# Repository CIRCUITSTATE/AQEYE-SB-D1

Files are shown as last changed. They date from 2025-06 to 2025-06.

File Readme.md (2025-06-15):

# AQEYE-SB-D1

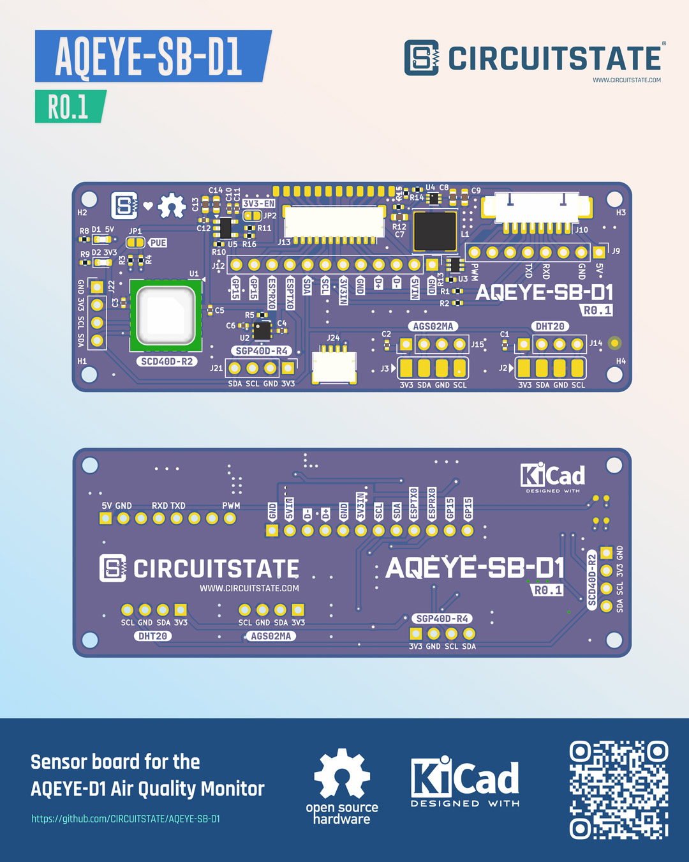
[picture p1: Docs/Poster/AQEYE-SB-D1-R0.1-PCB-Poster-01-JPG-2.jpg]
AQEYE-SB-D1 R0.1 Poster


[**AQEYE-SB-D1**](https://github.com/CIRCUITSTATE/AQEYE-SB-D1) is a PCB designed to hold the sensors for the AQEYE-D1 Air Quality Monitor project by CIRCUITSTATE Electronics. The board is designed to be connected to either the [**ESP32-S3-Touch-LCD-2.8**](https://www.waveshare.com/esp32-s3-touch-lcd-2.8.htm) from Waveshare or the AQEYE-MB-D1 main board. A separate sensor board was designed to keep the sensitive components away from external interferences such as noise, heat and other effects. This also makes it easier to replace the sensors or to add new sensors in the future without having to redesign the main board. AQEYE-SB-D1 is a completely open-source hardware (OSHW) project designed in the **KiCad** open-source EDA tool. **SB** stands for Sensor Board and **D1** is the first design variant of this project. You can download the source files of this design, modify them and redistribute them as you wish.

## Features

- Sensors
  - **Asair DHT20** temperature and humidity sensor.
  - **Asair AGS02MA** TVOC (Total Volatile Organic Compounds) sensor.
  - **Winsen ZH06** PM (Particulate Matter) sensor with PM1.0, PM2.5, PM10 measurement.
  - **Sensirion SCD40-D-R2** CO2 (Carbon Dioxide) sensor.
  - **Sensirion SGP40-D-R4** TVOC sensor.
- Connectors and solderpads for all sensors.
- 12-pin JST-SH connector for connecting to the main board.
- Selectable I2C pull-up resistors.
- **TPS61023** +5V boost converter to generate 5V from the 3.3V input for sensors that require 5V.
  - Output controlled by a GPIO pin.
- **AP22804AW5** based +3.3V load switch to control the power.
  - Controlled by a GPIO pin.
  - Jumper pad to constant enable.
- **LM66100DCKR** ideal diode based voltage ORing selector and reverse polarity protection for the 5V rail.
- Power indication LEDs for both 3.3V and 5V rails.
- Four M2 mounting holes.

## Design

- **Parent Project:** AQEYE-SB
- **Variant:** [AQEYE-SB-D1](https://github.com/CIRCUITSTATE/AQEYE-SB-D1)
- **Author:** Vishnu Mohanan (@vishnumaiea, @vizmohanan)
- **Latest Revision:** `R0.1`
- **Layer Count:** 2
- **Thickness:** 1.6 mm
- **Dimensions:** 80 x 30 mm
- **EDA Tool:** KiCad V9
- **License:** MIT

## Contributing

If you would like to contribute this project, you are welcome to post issues and feature requests on the **Issues** page. If you fork this project and created a new variant, you can let us know about it and get a unique identifier assigned for your project. The ID takes the following form.

```
Y<digit><letter><digit>
```

`Y` – Constant prefix.

`<digit>` – Digits from 0–9

`<letter>` – Characters from A–Z.

**Examples:**

```
Y1A1
Y1A2
Y2B1
Y3C4
```

The forked project should then be renamed to `AQEYE-SB-D1-<ID>` form.

**Guidelines:**

- IDs are assigned upon request. You can create a new issue to request a new ID once a fork is created. Keep the issue title as `Request New ID` and include a link to your fork in the description.
- You can either request a new ID that you like and that is already not chosen, or allow us to choose an ID for you.
- You should rename the original source files with the `AQEYE-SB-D1-<ID>` format.
- On the PCB, you can place the name of the project as `AQEYE-SB-D1` and keep the ID as a standalone text on any visible layers.
- Once a unique ID is assigned to a forked project, the revision should be reset to `R0.1`. Do not keep the original revision of the project.

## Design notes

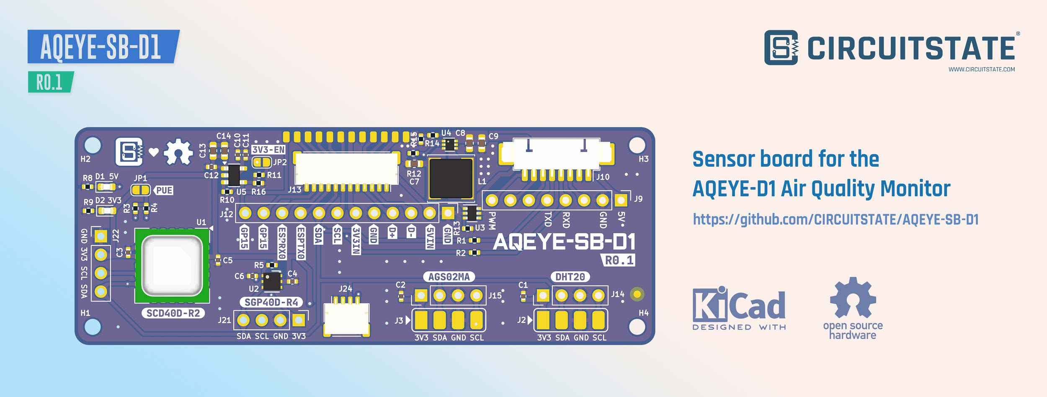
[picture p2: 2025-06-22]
Docs/Poster/AQEYE-SB-D1-R0.1-PCB-Poster-02-JPG-2.jpg

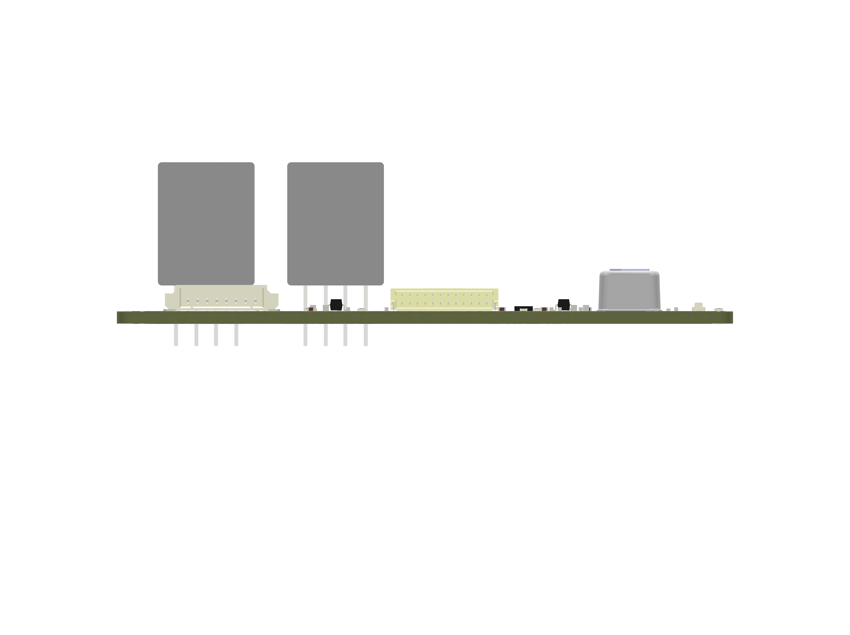
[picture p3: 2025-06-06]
Export/R0.1/2025-06-06/Renders/AQEYE-SB-D1-R0.1-PCB-Back-06062025-1.png

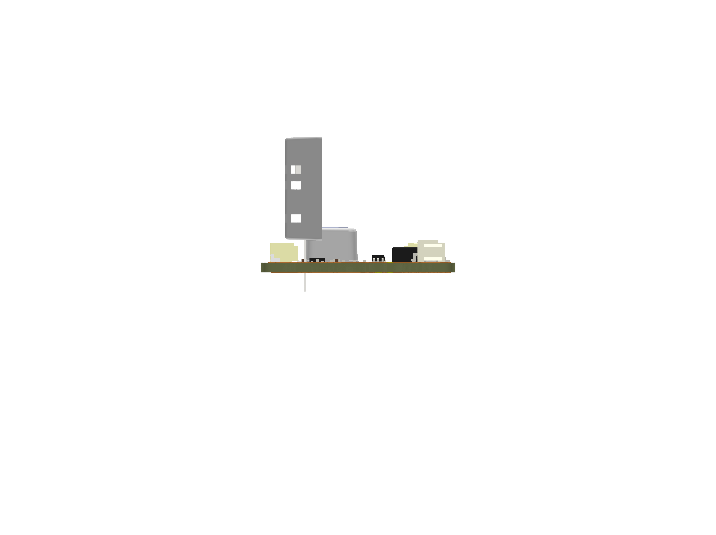
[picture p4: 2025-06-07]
Export/R0.1/2025-06-08/Renders/AQEYE-SB-D1-R0.1-PCB-Right-08062025-1.png

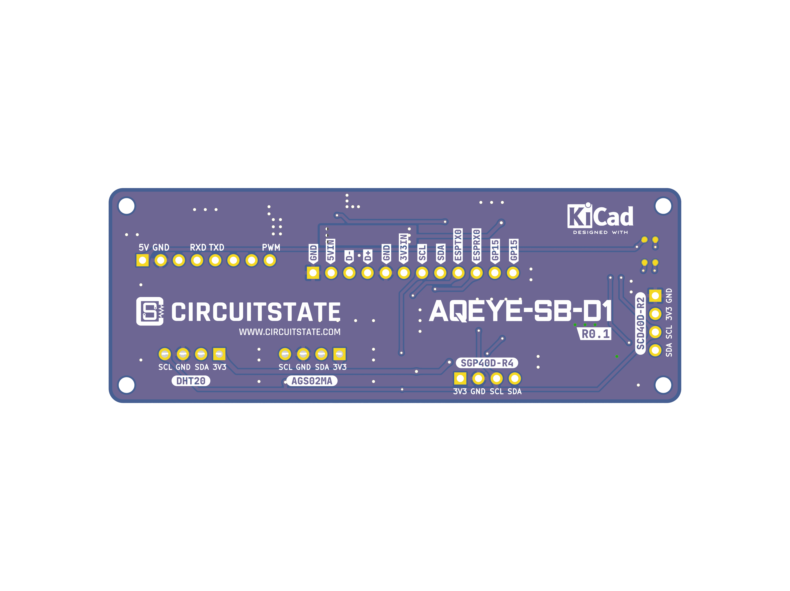
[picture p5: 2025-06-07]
Export/R0.1/2025-06-08/Renders/AQEYE-SB-D1-R0.1-PCB-Paste-Back-08062025-1.png

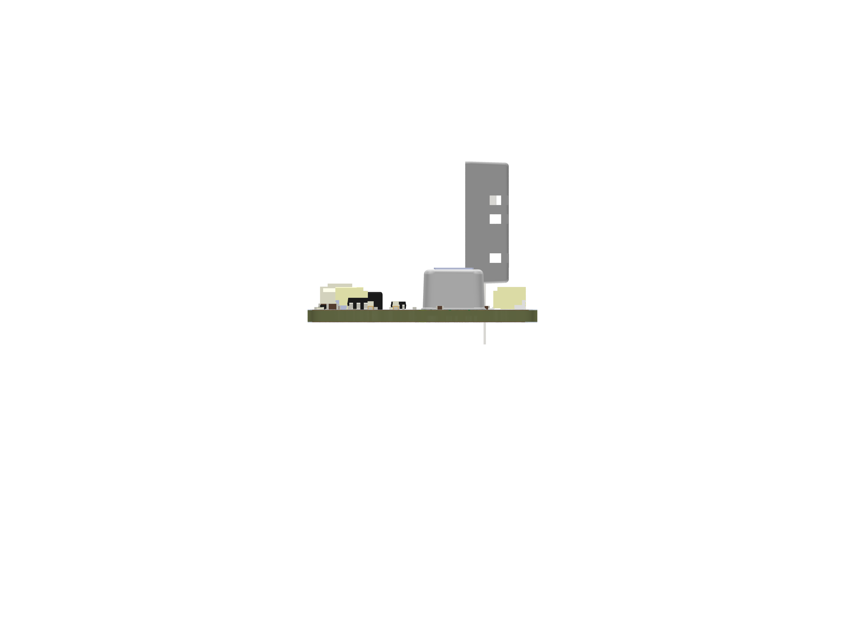
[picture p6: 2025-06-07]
Export/R0.1/2025-06-08/Renders/AQEYE-SB-D1-R0.1-PCB-Left-08062025-1.png

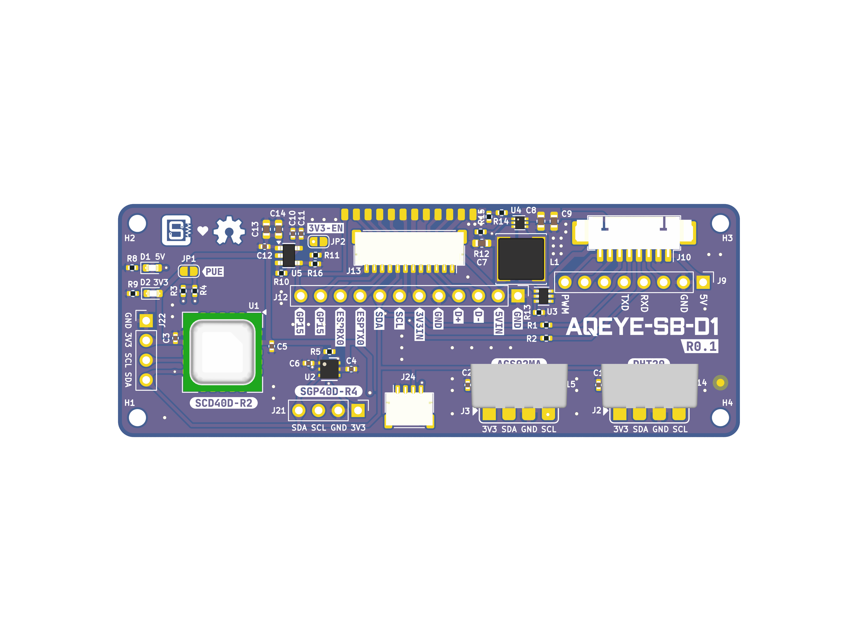
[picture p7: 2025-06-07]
Export/R0.1/2025-06-08/Renders/AQEYE-SB-D1-R0.1-PCB-Paste-Front-08062025-1.png

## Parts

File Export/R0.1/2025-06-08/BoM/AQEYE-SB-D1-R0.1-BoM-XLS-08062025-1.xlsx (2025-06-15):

# | Reference | Value | Name | Qty | DNP | Footprint | MPN | MFR | Alt MPN
1 | C1,C2,C3,C5,C10,C12 | 0.1uF |  | 6 |  | Capacitor_SMD:C_0402_1005Metric | CC0402KRX5R6BB104 | Yageo
2 | C4,C6,C11 | 10uF |  | 3 |  | Capacitor_SMD:C_0402_1005Metric | GRM155R61A106ME11D | Murata | CL05A106MP5NUNC, GRM155R61A106ME44D, CGA0402X5R106M100GT, 0402X106M100NT
3 | C7,C8,C9,C13,C14 | 22uF |  | 5 |  | Capacitor_SMD:C_0603_1608Metric | CL10A226MP8NUNE | Samsung
4 | D1 | 5V_LED | 5V_LED | 1 |  | LED_SMD:LED_0603_1608Metric | XL-1608SURC-06 | XINGLIGHT | 19-21SURC/S530-A2/TR8
5 | D2 | 3V3_LED | 3V3_LED | 1 |  | LED_SMD:LED_0603_1608Metric | XL-1608UOC-06 | XINGLIGHT
6 | H1,H2,H3,H4,J1,J2,J3,J4,J5,J6,J7,J8,J9,J11,J12,J16,J17,J18,J19,J20,J21,J22,JP1,JP2,TP1,TP2,TP3,TP4 | +3.3V,+5V,3V3_EN,3V3_LED_M,3V3_LED_P,5V_LED_M,5V_LED_P,AGS02MA_PAD,DHT20_PAD,ESP_RXD0,ESP_TXD0,GND,GPIO15,GPIO18,I2C_PUE,I2C_SCL,I2C_SDA,MB_PINS,Mounting Hole,SCD40-D-R2_CONN,SGP40-D-R4_CONN,USB_D+,USB_D-,ZH06_Pin | +3.3V,+5V,3V3_EN,3V3_LED_M,3V3_LED_P,5V_LED_M,5V_LED_P,AGS02MA_PAD,DHT20_PAD,ESP_RXD0,ESP_TXD0,GND,GPIO15,GPIO18,I2C_PUE,I2C_SCL,I2C_SDA,MB_PINS,Mounting Hole,SCD40-D-R2_CONN,SGP40-D-R4_CONN,USB_D+,USB_D-,ZH06_Pin | 28 | YES | CSE_Solder-Jumper:Solder-Jumper-1x2_P1.3mm_Open_Rounded_1.0x1.2mm,CSE_Solderpads:Solderpad_1x04_P2.54mm_Rounded_Rectangle,CSE_Solderpads:Solderpad_Rounded_Rectangle_0.9x1.5mm,Connector_PinHeader_2.54mm:PinHeader_1x04_P2.54mm_Vertical,Connector_PinHeader_2.54mm:PinHeader_1x08_P2.54mm_Vertical,Connector_PinHeader_2.54mm:PinHeader_1x12_P2.54mm_Vertical,MountingHole:MountingHole_2.2mm_M2_DIN965,SparkFun-Connector:TestPoint-0.75mm | DNP | DNP
7 | J10 | ZH06_PicoBlade | ZH06_PicoBlade | 1 |  | Connector_Molex:Molex_PicoBlade_53261-0871_1x08-1MP_P1.25mm_Horizontal | 0532610871 | Molex
8 | J13 | MB_CONNECTOR | MB_CONNECTOR | 1 |  | CSE_Connector_JST_SH:JST_SH_SM12B-SRSS-TB_1x12-1MP_P1.00mm_Horizontal | SM12B-SRSS-TB | JST
9 | J14 | DHT20 | DHT20 | 1 |  | Connector_PinHeader_2.54mm:PinHeader_1x04_P2.54mm_Vertical | DHT20 | Asair
10 | J15 | AGS02MA | AGS02MA | 1 |  | Connector_PinHeader_2.54mm:PinHeader_1x04_P2.54mm_Vertical | AGS02MA | Asair
11 | J23 | WS_TVOC | WS_TVOC | 1 | YES |  | DNP | DNP
12 | J24 | STEMMA-QT | STEMMA-QT | 1 |  | CSE_Connector_JST_SH:JST_SH_SM04B-SRSS-TB_1x04-1MP_P1.00mm_Horizontal_2 | SM04B-SRSS-TB | JST
13 | L1 | 1uH |  | 1 |  | Inductor_SMD:L_Changjiang_FNR6020S | CD54-1R0M | SHUOXING
14 | R1,R2,R11 | 1K |  | 3 |  | Resistor_SMD:R_0402_1005Metric | RC0402FR-071KL | Yageo
15 | R3,R4 | 5.1K |  | 2 |  | Resistor_SMD:R_0402_1005Metric | RC0402FR-075K1L | Yageo
16 | R5 | 4.7R |  | 1 |  | Resistor_SMD:R_0402_1005Metric | RC0402FR-074R7L | Yageo
17 | R6,R7 | 1K |  | 2 | YES | Resistor_SMD:R_0402_1005Metric | RC0402FR-071KL | Yageo
18 | R8 | 330R |  | 1 |  | Resistor_SMD:R_0402_1005Metric | RC0402FR-07330RL | Yageo
19 | R9 | 220R |  | 1 |  | Resistor_SMD:R_0402_1005Metric | RC0402FR-7D220RL | Yageo
20 | R10,R12,R13,R16 | 10K |  | 4 |  | Resistor_SMD:R_0402_1005Metric | RC0402FR-0710KL | Yageo
21 | R14 | 732K |  | 1 |  | Resistor_SMD:R_0402_1005Metric | RC0402FR-07732KL | Yageo
22 | R15 | 100K |  | 1 |  | Resistor_SMD:R_0402_1005Metric | RC0402FR-07100KL | Yageo
23 | U1 | SCD40-D-R2 | CO2 Sensor | 1 |  | Sensor:Sensirion_SCD4x-1EP_10.1x10.1mm_P1.25mm_EP4.8x4.8mm | SCD40-D-R2 | Sensirion
24 | U2 | SGP40-D-R4 | TVOC Sensor | 1 |  | CSE_Package_DFN_QFN:DFN-6-1EP_2.44x2.44mm_P0.8mm_EP1.25x1.7mm | SGP40-D-R4 | Sensirion
25 | U3 | LM66100DCKR |  | 1 |  | Package_TO_SOT_SMD:SOT-363_SC-70-6 | LM66200DRLR | Texas Instruments
26 | U4 | TPS61023 |  | 1 |  | Package_TO_SOT_SMD:SOT-563 | TPS61023DRLR | Texas Instruments
27 | U5 | AP22804AW5 | Load Switch | 1 |  | Package_TO_SOT_SMD:SOT-23-5 | AP22804AW5-7 | Diodes Inc

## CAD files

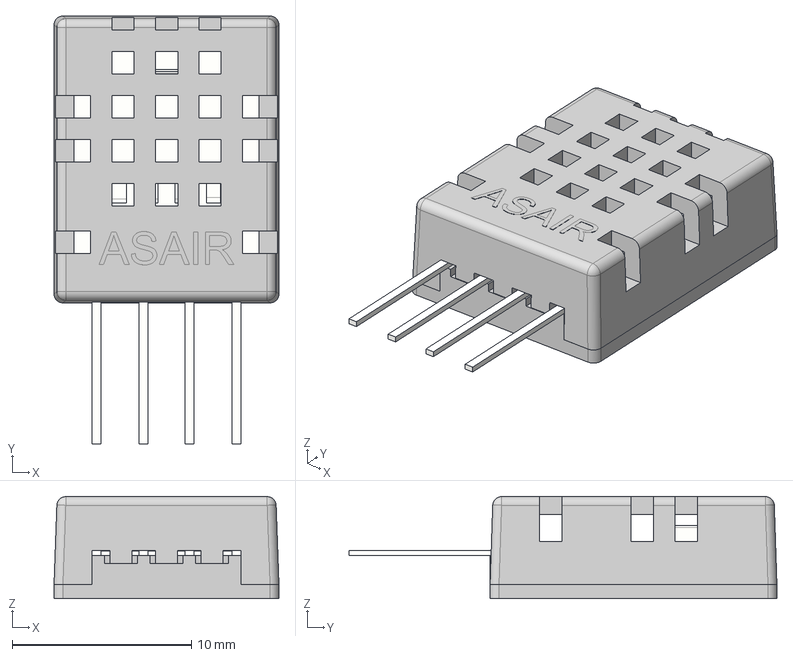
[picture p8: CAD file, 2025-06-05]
Parts/3D-Models/ASAIR-DHT20.step
12.6 x 23.9 x 5.71 mm

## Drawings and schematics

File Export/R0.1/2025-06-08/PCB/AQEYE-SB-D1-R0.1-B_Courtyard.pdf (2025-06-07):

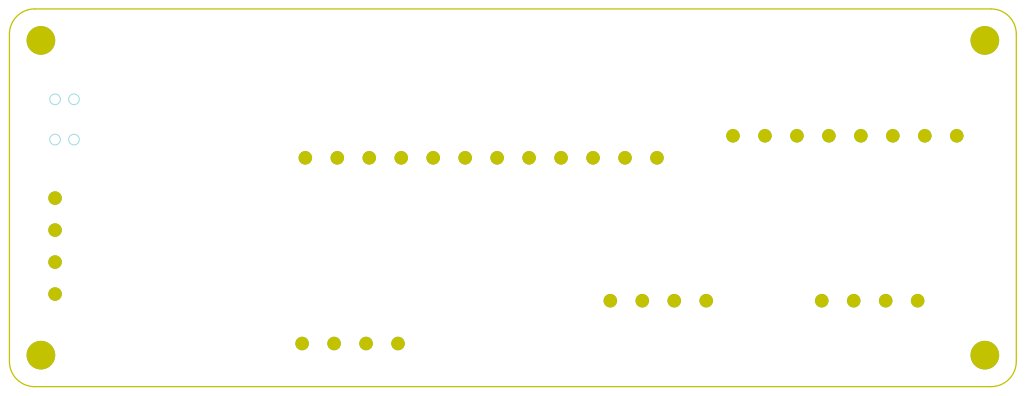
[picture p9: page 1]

Id: 1/1 Title: AQEYE-SB-D1

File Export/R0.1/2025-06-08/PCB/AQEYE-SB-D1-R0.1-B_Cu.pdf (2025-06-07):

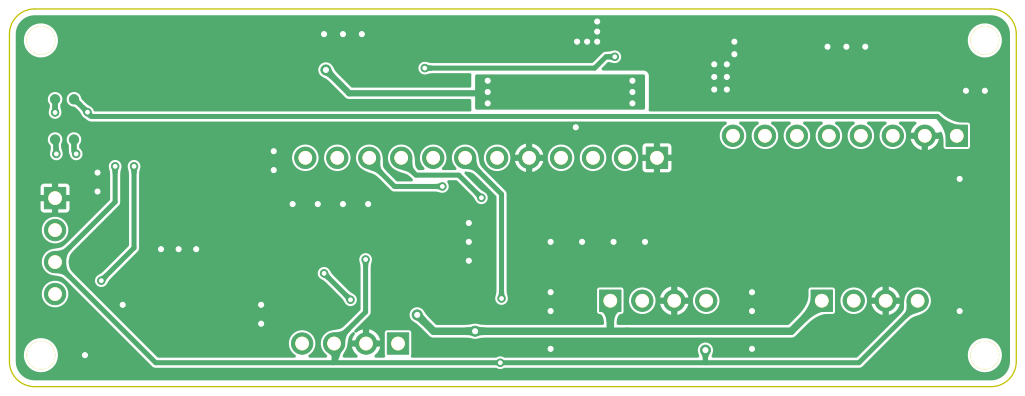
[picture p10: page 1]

Id: 1/1 Title: AQEYE-SB-D1

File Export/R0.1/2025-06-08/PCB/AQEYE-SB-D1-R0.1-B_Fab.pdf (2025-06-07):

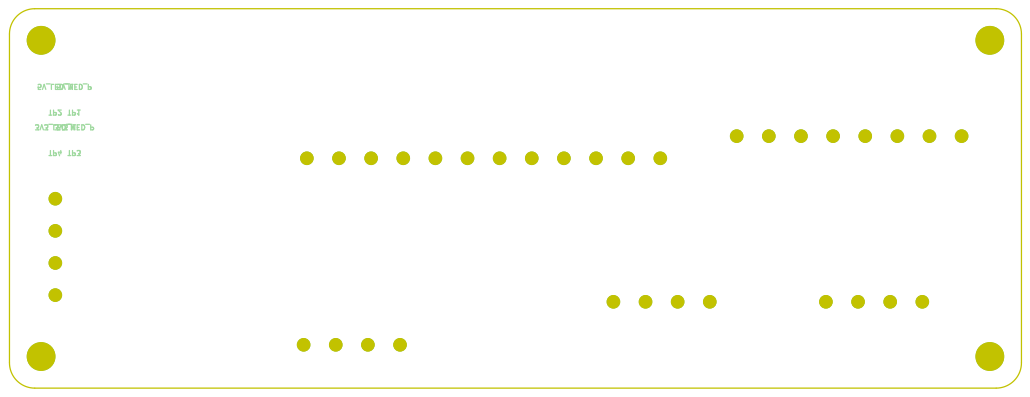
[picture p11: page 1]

Id: 1/1 Title: AQEYE-SB-D1

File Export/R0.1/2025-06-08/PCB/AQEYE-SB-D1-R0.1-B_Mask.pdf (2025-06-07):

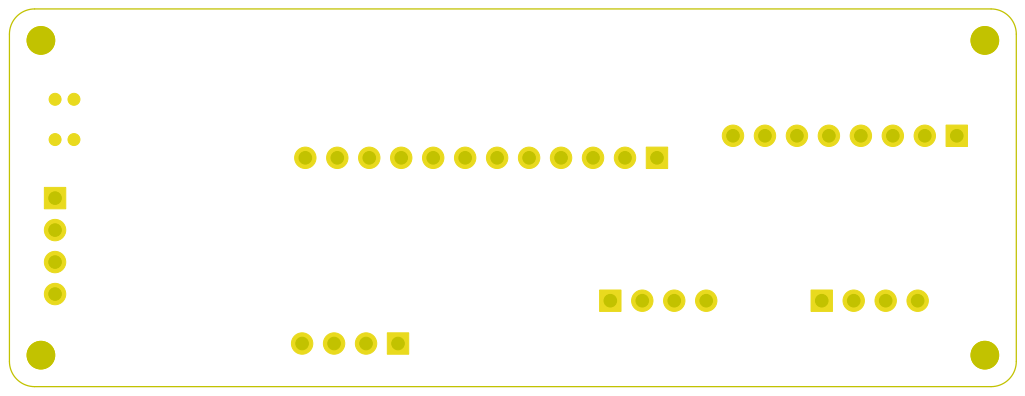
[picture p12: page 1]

Id: 1/1 Title: AQEYE-SB-D1

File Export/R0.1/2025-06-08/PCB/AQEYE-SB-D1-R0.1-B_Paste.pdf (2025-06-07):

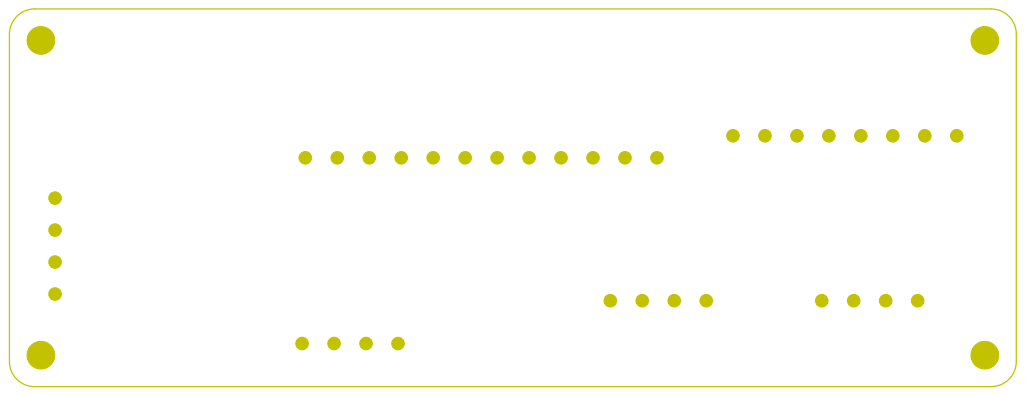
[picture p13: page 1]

Id: 1/1 Title: AQEYE-SB-D1

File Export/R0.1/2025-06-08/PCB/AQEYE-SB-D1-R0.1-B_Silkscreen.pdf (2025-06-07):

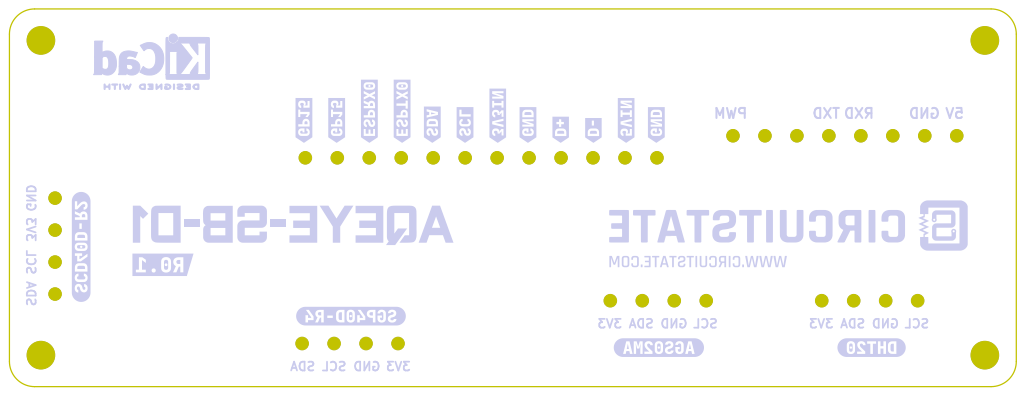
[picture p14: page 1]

Id: 1/1 Title: AQEYE-SB-D1

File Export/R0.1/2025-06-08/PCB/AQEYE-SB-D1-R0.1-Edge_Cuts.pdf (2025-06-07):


Id: 1/1 Title: AQEYE-SB-D1

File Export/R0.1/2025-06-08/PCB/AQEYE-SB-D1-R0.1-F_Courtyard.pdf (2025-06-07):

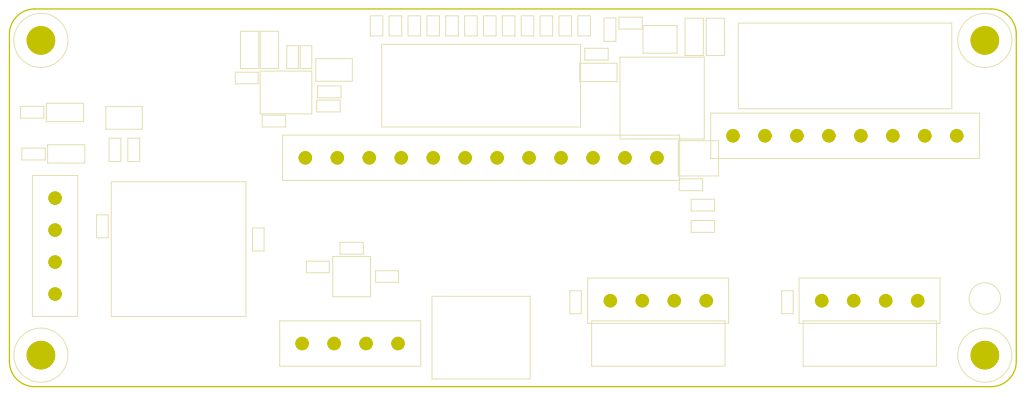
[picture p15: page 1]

Id: 1/1 Title: AQEYE-SB-D1

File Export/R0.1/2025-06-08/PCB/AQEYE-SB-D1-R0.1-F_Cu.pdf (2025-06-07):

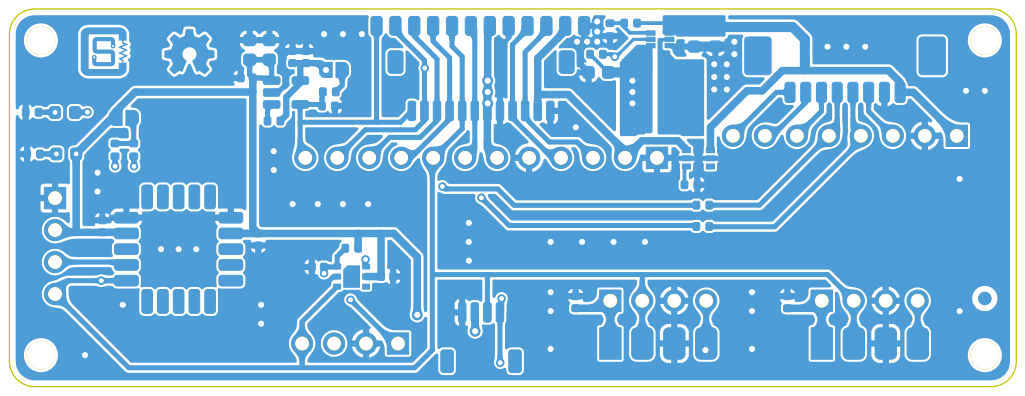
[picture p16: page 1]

Id: 1/1 Title: AQEYE-SB-D1

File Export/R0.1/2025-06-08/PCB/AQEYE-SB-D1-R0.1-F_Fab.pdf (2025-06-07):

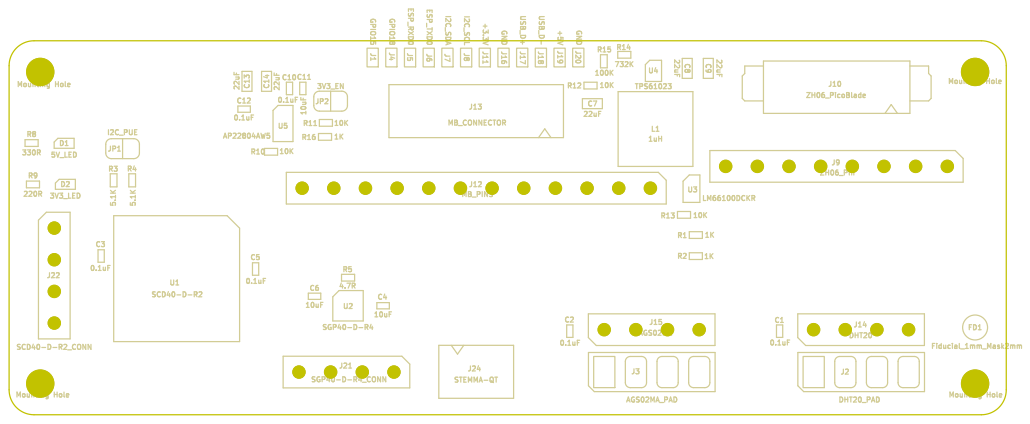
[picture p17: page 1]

Id: 1/1 Title: AQEYE-SB-D1

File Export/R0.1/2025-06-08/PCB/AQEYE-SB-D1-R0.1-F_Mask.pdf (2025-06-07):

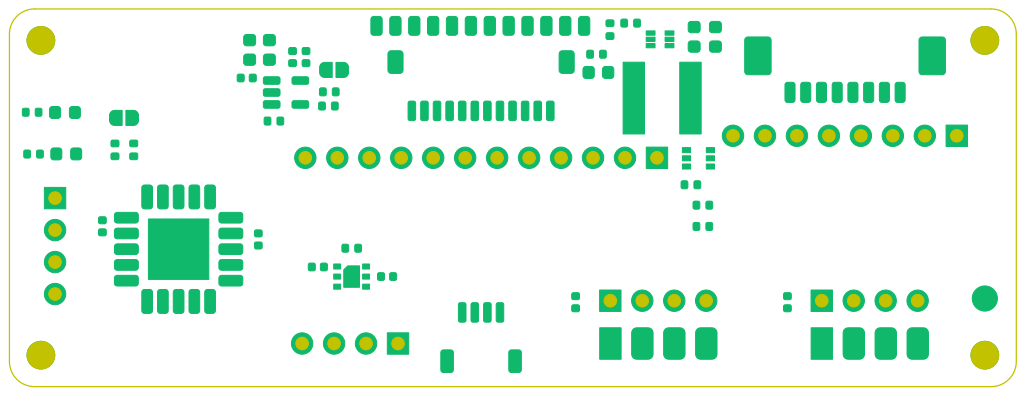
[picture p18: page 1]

Id: 1/1 Title: AQEYE-SB-D1

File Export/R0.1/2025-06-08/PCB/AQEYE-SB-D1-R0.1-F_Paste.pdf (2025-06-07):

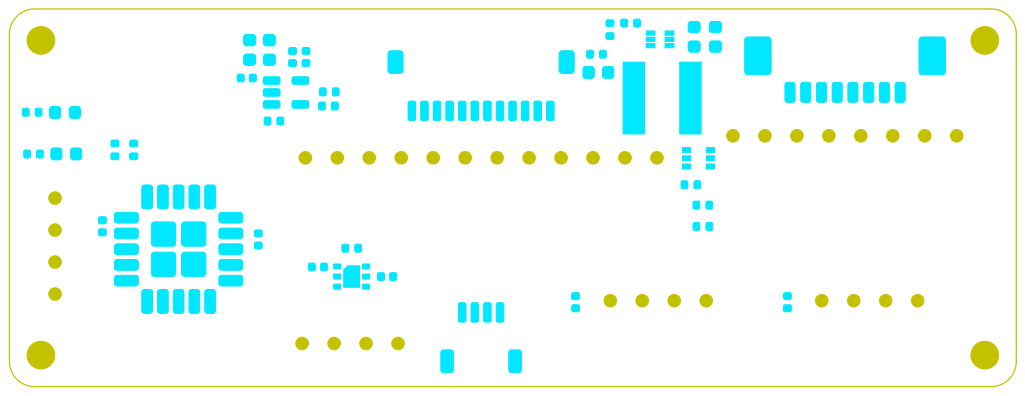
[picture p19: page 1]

Id: 1/1 Title: AQEYE-SB-D1

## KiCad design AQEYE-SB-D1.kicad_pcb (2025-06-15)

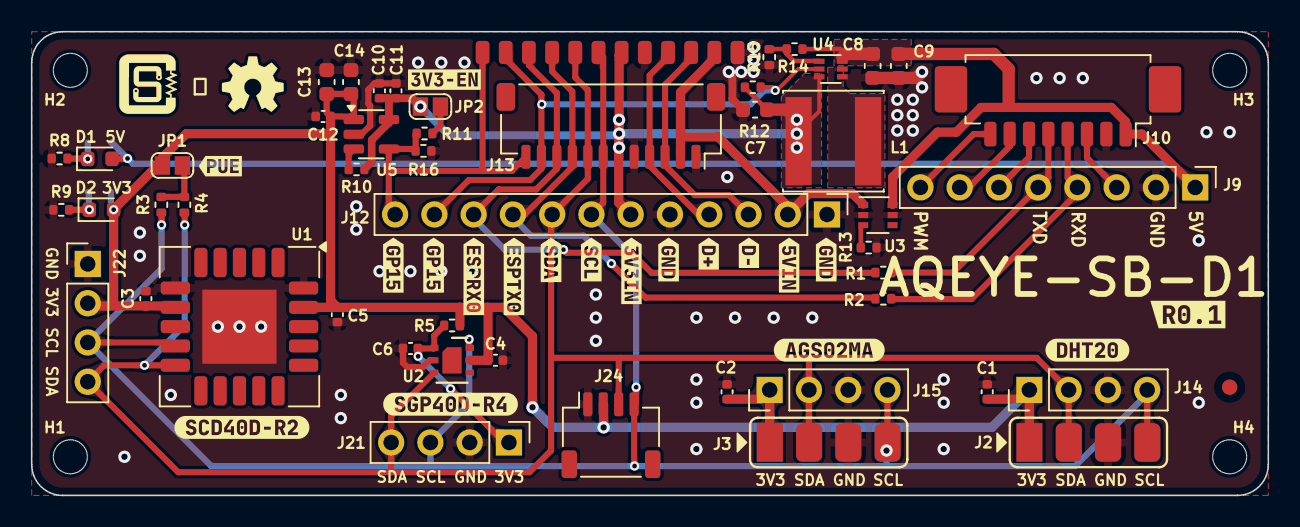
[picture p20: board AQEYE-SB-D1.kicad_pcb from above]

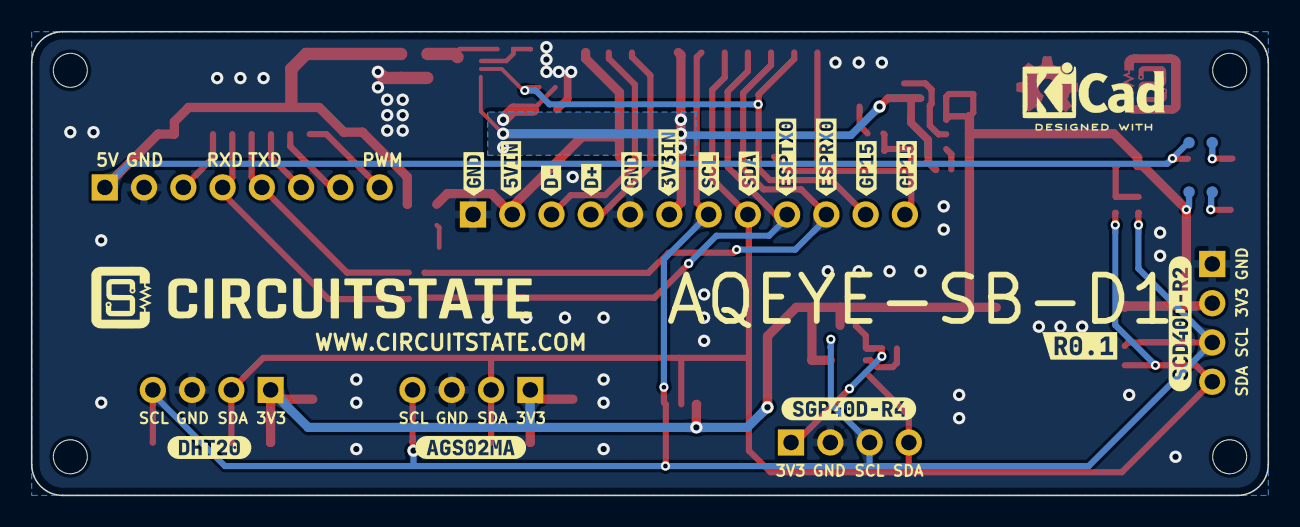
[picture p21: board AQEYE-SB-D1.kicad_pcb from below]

Board: 2 copper layers, 80.0 x 30.0 mm, 105 parts (21 on the bottom side), 24 nets.

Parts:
C1, C2, C3, C5, C10, C12: 0.1uF; C_0402_1005Metric
C4, C6, C11: 10uF; C_0402_1005Metric
C7, C8, C9, C13, C14: 22uF; C_0603_1608Metric
D1: 5V_LED; LED_0603_1608Metric
D2: 3V3_LED; LED_0603_1608Metric
H1, H2, H3, H4: Mounting Hole; MountingHole_2.2mm_M2_DIN965
J1: GPIO15; Solderpad_Rounded_Rectangle_0.9x1.5mm
J2: DHT20_PAD; Solderpad_1x04_P2.54mm_Rounded_Rectangle
J3: AGS02MA_PAD; Solderpad_1x04_P2.54mm_Rounded_Rectangle
J4: GPIO18; Solderpad_Rounded_Rectangle_0.9x1.5mm
J5: ESP_RXD0; Solderpad_Rounded_Rectangle_0.9x1.5mm
J6: ESP_TXD0; Solderpad_Rounded_Rectangle_0.9x1.5mm
J7: I2C_SDA; Solderpad_Rounded_Rectangle_0.9x1.5mm
J8: I2C_SCL; Solderpad_Rounded_Rectangle_0.9x1.5mm
J9: ZH06_Pin; PinHeader_1x08_P2.54mm_Vertical
J10: ZH06_PicoBlade; Molex_PicoBlade_53261-0871_1x08-1MP_P1.25mm_Horizontal
J11: +3.3V; Solderpad_Rounded_Rectangle_0.9x1.5mm
J12: MB_PINS; PinHeader_1x12_P2.54mm_Vertical
J13: MB_CONNECTOR; JST_SH_SM12B-SRSS-TB_1x12-1MP_P1.00mm_Horizontal
J14: DHT20; PinHeader_1x04_P2.54mm_Vertical
J15: AGS02MA; PinHeader_1x04_P2.54mm_Vertical
J16, J20: GND; Solderpad_Rounded_Rectangle_0.9x1.5mm
J17: USB_D+; Solderpad_Rounded_Rectangle_0.9x1.5mm
J18: USB_D-; Solderpad_Rounded_Rectangle_0.9x1.5mm
J19: +5V; Solderpad_Rounded_Rectangle_0.9x1.5mm
J21: SGP40-D-R4_CONN; PinHeader_1x04_P2.54mm_Vertical
J22: SCD40-D-R2_CONN; PinHeader_1x04_P2.54mm_Vertical
J24: STEMMA-QT; JST_SH_SM04B-SRSS-TB_1x04-1MP_P1.00mm_Horizontal_2
JP1: I2C_PUE; Solder-Jumper-1x2_P1.3mm_Open_Rounded_1.0x1.2mm
JP2: 3V3_EN; Solder-Jumper-1x2_P1.3mm_Open_Rounded_1.0x1.2mm
L1: 1uH; L_Changjiang_FNR6020S
R1, R2, R11: 1K; R_0402_1005Metric
R3, R4: 5.1K; R_0402_1005Metric
R5: 4.7R; R_0402_1005Metric
R8: 330R; R_0402_1005Metric
R9: 220R; R_0402_1005Metric
R10, R12, R13, R16: 10K; R_0402_1005Metric
R14: 732K; R_0402_1005Metric
R15: 100K; R_0402_1005Metric
TP1: 5V_LED_P; TestPoint-0.75mm
TP2: 5V_LED_M; TestPoint-0.75mm
TP3: 3V3_LED_P; TestPoint-0.75mm
TP4: 3V3_LED_M; TestPoint-0.75mm
U1: SCD40-D-R2; Sensirion_SCD4x-1EP_10.1x10.1mm_P1.25mm_EP4.8x4.8mm
U2: SGP40-D-R4; DFN-6-1EP_2.44x2.44mm_P0.8mm_EP1.25x1.7mm
U3: LM66100DCKR; SOT-363_SC-70-6
U4: TPS61023; SOT-563
U5: AP22804AW5; SOT-23-5
kibuzzard-68408B8A, kibuzzard-68408B8A#2: G***; kibuzzard-68408B8A
kibuzzard-68408BAF, kibuzzard-68408BAF#2: G***; kibuzzard-68408BAF
kibuzzard-68408BD4, kibuzzard-68408BD4#2: G***; kibuzzard-68408BD4
kibuzzard-68408D06, kibuzzard-68408D06#2: G***; kibuzzard-68408D06
kibuzzard-68408D87, kibuzzard-68408D87#2: G***; kibuzzard-68408D87
kibuzzard-68408E5C: G***; kibuzzard-68408E5C
kibuzzard-68408E86: G***; kibuzzard-68408E86
kibuzzard-684088E7, kibuzzard-684088E7#2, kibuzzard-684088E7#3, kibuzzard-684088E7#4: G***; kibuzzard-684088E7
kibuzzard-6840890A, kibuzzard-6840890A#2, kibuzzard-6840890A#3, kibuzzard-6840890A#4: G***; kibuzzard-6840890A
kibuzzard-6840894F, kibuzzard-6840894F#2: G***; kibuzzard-6840894F
kibuzzard-6840895D, kibuzzard-6840895D#2: G***; kibuzzard-6840895D
kibuzzard-68408942, kibuzzard-68408942#2: G***; kibuzzard-68408942
kibuzzard-68408956, kibuzzard-68408956#2: G***; kibuzzard-68408956
kibuzzard-68408963, kibuzzard-68408963#2: G***; kibuzzard-68408963
kibuzzard-68408966, kibuzzard-68408966#2: G***; kibuzzard-68408966
kibuzzard-68408979, kibuzzard-68408979#2: G***; kibuzzard-68408979
kibuzzard-68408981, kibuzzard-68408981#2: G***; kibuzzard-68408981

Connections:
+3.3V: C1.1, C2.1, C3.1, C4.1, C5.1, C12.1, C13.1, C14.1, D2.2 (A), J2.1, J3.1, J14.1, J15.1, J22.2, J24.2, JP1.1 (A), R5.1, TP3.1, U1.7 (VDD), U1.19 (VDD), U2.5 (VDDH), U5.1 (OUT)
+3.3V_IN: C7.1, C10.1, C11.1, J11.1, J12.6, J13.6, JP2.2 (B), L1.1, R10.2, R12.2, U4.3 (VIN), U5.5 (IN)
+5V: C8.1, C9.1, D1.2 (A), J9.1, J10.1, R14.2, TP1.1, U3.6 (VOUT), U4.6 (VOUT)
+5V_IN: J12.2, J13.2, J19.1, U3.1 (VIN)
/ESP_RXD0: J5.1, J12.10, J13.10, R1.2
/ESP_TXD0: J6.1, J12.9, J13.9, R2.2
/GPIO15: J1.1, J12.12, J13.12, R11.1, R16.2, U5.4 (EN)
/GPIO18: J4.1, J12.11, J13.11, R12.1, U4.2 (EN)
/I2C_SCL: J2.4, J3.4, J8.1, J12.7, J13.7, J14.4, J15.4, J21.3, J22.3, J24.4, R3.1, U1.9 (SCL), U2.6 (SCL)
/I2C_SDA: J2.2, J3.2, J7.1, J12.8, J13.8, J14.2, J15.2, J21.4, J22.4, J24.3, R4.1, U1.10 (SDA), U2.3 (SDA)
/USB_D+: J12.4, J13.4, J17.1
/USB_D-: J12.3, J13.3, J18.1
GND: C1.2, C2.2, C3.2, C4.2, C5.2, C6.1, C7.2, C8.2, C9.2, C10.2, C11.2, C12.2, C13.2, C14.2, J2.3, J3.3, J9.2, J10.2, J12.1, J12.5, J13.1, J13.5, J14.3, J15.3, J16.1, J20.1, J21.2, J22.1, J24.1, R8.1, R9.1, R13.1, R15.1, R16.1, U1.6 (GND), U1.20 (GND), U1.21 (GND), U2.2 (GND), U3.2 (GND), U3.5 (ST), U4.4 (GND), U5.2 (GND)
unnamed: D1.1 (K), R8.2, TP2.1
unnamed: D2.1 (K), R9.2, TP4.1
unnamed: J9.4, J10.4, R2.1
unnamed: J9.5, J10.5, R1.1
unnamed: C6.2, J21.1, R5.2, U2.1 (VDD)
unnamed: JP1.2 (B), R3.2, R4.2
unnamed: JP2.1 (A), R11.2
unnamed: R13.2, U3.3 (CE)
unnamed: R14.1, R15.2, U4.1 (FB)
unnamed: L1.2, U4.5 (SW)
unnamed: R10.1, U5.3 (~FLG)

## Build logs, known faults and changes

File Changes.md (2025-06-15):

# Changes

#
### **+05:30 11:03:36 AM 15-06-2025, Sunday**

  - Added License file.

#
### **+05:30 10:56:55 AM 15-06-2025, Sunday**

  - Updated Readme.
  - Added poster image.
  - Generated PCB renders without the Asair sensors.

#
### **+05:30 05:03:43 PM 07-06-2025, Saturday**

  - Schematic
    - Realized that the main board can not supply 5V when the USB is not connected.
    - Added a `TPS61023` 5V boost converter to generate 5V from the 3.3V input.
    - Removed the 5V load switch since the 5V output can not be controlled via the boost converter.
    - The 5V converter enabled by default with a GPIO control.
    - Added `LM66100DCKR` single-channel ideal diode to connect the VBUS to the 5V rail.
    - Reset the annotations.
    - Updated the BoM.
  - PCB
    - Imported all changes to the PCB.
    - Placement and routing completed.
    - DRC passes.
    - Updated Fab layers.
    - Updated KiExport configuration.
      - New STEP and VRML options are added.
  - Generated manufacturing files.
  - No version change.

#
### **+05:30 06:52:30 PM 06-06-2025, Friday**

  - Schematic
    - Updated BoM.
    - Assigned all MPNs.
    - Added `Group by MPN-DNP` preset.
  - PCB
    - Imported all changes to the PCB.
    - Cleaned up the Fab layers.
    - Added CIRCUITSTATE logo and GitHub link to schematic.
    - Applied teardrops.
    - Added board stackup table and characteristics.
    - DRC passes.
  - Added KiExport configuration.
  - Added Git scripts.
  - Generated manufacturing files.

#
### **+05:30 09:57:26 PM 05-06-2025, Thursday**

  - Schematic
    - Completed the schematic.
    - Assigned all footprints.
    - Added net classes and colors.
    - ERC passes.
  - PCB
    - Imported all changes to the PCB.
    - Added PCB outline and arranged all of the components.
    - Added labels and logos.
    - Added design constraints.
    - Added a single fiducial on the top side.
    - Routing completed.
    - DRC passes.
    - Added dimensions.
    - Added missing 3D models.
  - TODO
    - Complete the BoM.
    - Recheck the board design constraints.
    - Cleanup the fab layers.
    - Add board stackup table and characteristics. 
    - Add more GND vias.
    - Add CIRCUITSTATE logo and GitHub link.
    - Generate manufacturing files.
  - Initial commit.
  - Added Changes and Readme files.
  - New Revision 🆕 `R0.1`.

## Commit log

2025-06-05 Initial commit
    - Schematic
    - Completed the schematic.
    - Assigned all footprints.
    - Added net classes and colors.
    - ERC passes.
    - PCB
    - Imported all changes to the PCB.
    - Added PCB outline and arranged all of the components.
    - Added labels and logos.
    - Added design constraints.
    - Added a single fiducial on the top side.
    - Routing completed.
    - DRC passes.
    - Added dimensions.
    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
    [AQEYE-SB-D1.kicad_pcb, AQEYE-SB-D1.kicad_sch, ASAIR-DHT20.step]
2025-06-06 Generated manufacturing files
    - Updated BoM.
    - Assigned all MPNs.
    - Added `Group by MPN-DNP` preset.
    - Cleaned up the Fab layers.
    - Added CIRCUITSTATE logo and GitHub link to schematic.
    - Applied teardrops.
    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
    [AQEYE-SB-D1-R0.1-BoM-CSV-06062025-1.csv, AQEYE-SB-D1-R0.1-BoM-XLS-06062025-1.xlsx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]
2025-06-07 Added 5V boost converter
    - Realized that the main board can not supply 5V when the USB is not connected.
    - Added a `TPS61023` 5V boost converter to generate 5V from the 3.3V input.
    - Removed the 5V load switch since the 5V output can not be controlled via the boost converter.
    - The 5V converter enabled by default with a GPIO control.
    - Added `LM66100DCKR` single-channel ideal diode to connect the VBUS to the 5V rail.
    - Reset the annotations.
    - Updated the BoM.
    - Placement and routing completed.
    - Updated Fab layers.
    - Updated KiExport configuration.
    - New STEP and VRML options are added.
    - Generate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
    [AQEYE-SB-D1-R0.1-BoM-CSV-08062025-1.csv, AQEYE-SB-D1-R0.1-BoM-XLS-08062025-1.xlsx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]
2025-06-15 Updated Readme
    - Added poster image.
    - Generated PCB renders without the Asair sensors.
    [AQEYE-SB-D1-R0.1-BoM-XLS-08062025-1.xlsx, AQEYE-SB-D1.kicad_pcb, AQEYE-SB-D1.kicad_sch]
2025-06-22 Added new banner image
    [AQEYE-SB-D1.kicad_sch]

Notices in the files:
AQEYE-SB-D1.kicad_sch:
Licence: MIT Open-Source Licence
